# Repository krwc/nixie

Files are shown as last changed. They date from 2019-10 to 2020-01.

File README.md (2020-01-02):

# Another Nixie Clock, because why not?

When my journey into the world of electronics started, a friend of mine has shown me the
beautiful creations capable of presenting time using cold cathode tubes. Ever since then,
I wanted to create something similar, as it seemed like a pretty cool thing to do!

After some time, and two PCB revisions, the clock was actually useful, wasn't exploding,
and was looking quite neat overall to me.


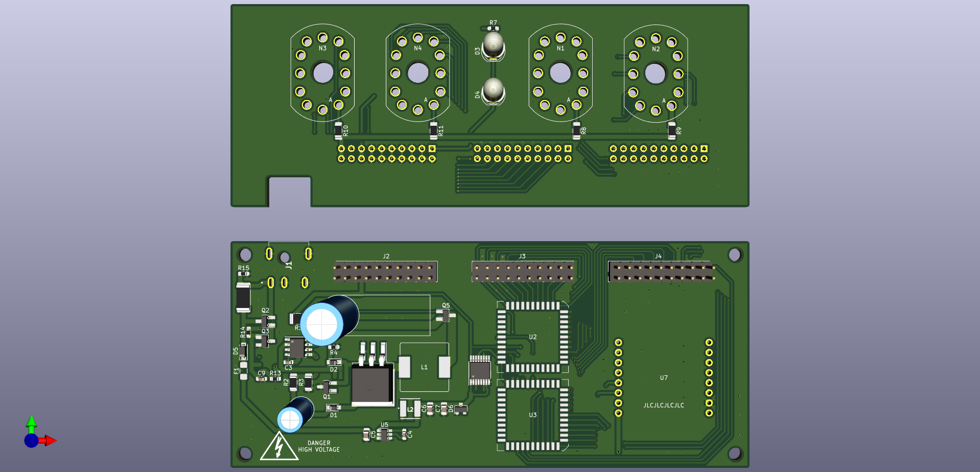
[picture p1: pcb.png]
PCB


# Safety

- The high voltage trace clearance is enforced to be 0.4mm
- There's a 1A slow fuse on the input
- There's a slow start mechanism implemented on the input, preventing high transient
  current during startup

Anyway, if you intend to use it, please do it on your own risk. Keep in mind, I'm not
a professional PCB designer, nor have a proper electrical education background.

# Acknolwedgements

- The power supply design is based on https://threeneurons.wordpress.com/nixie-power-supply/,
  and the datasheet of MC33063 itself. It is integrated into the main PCB.

- Wemos KiCad model was found somewhere on the internet, unfortunately I can't remember where
  exactly.

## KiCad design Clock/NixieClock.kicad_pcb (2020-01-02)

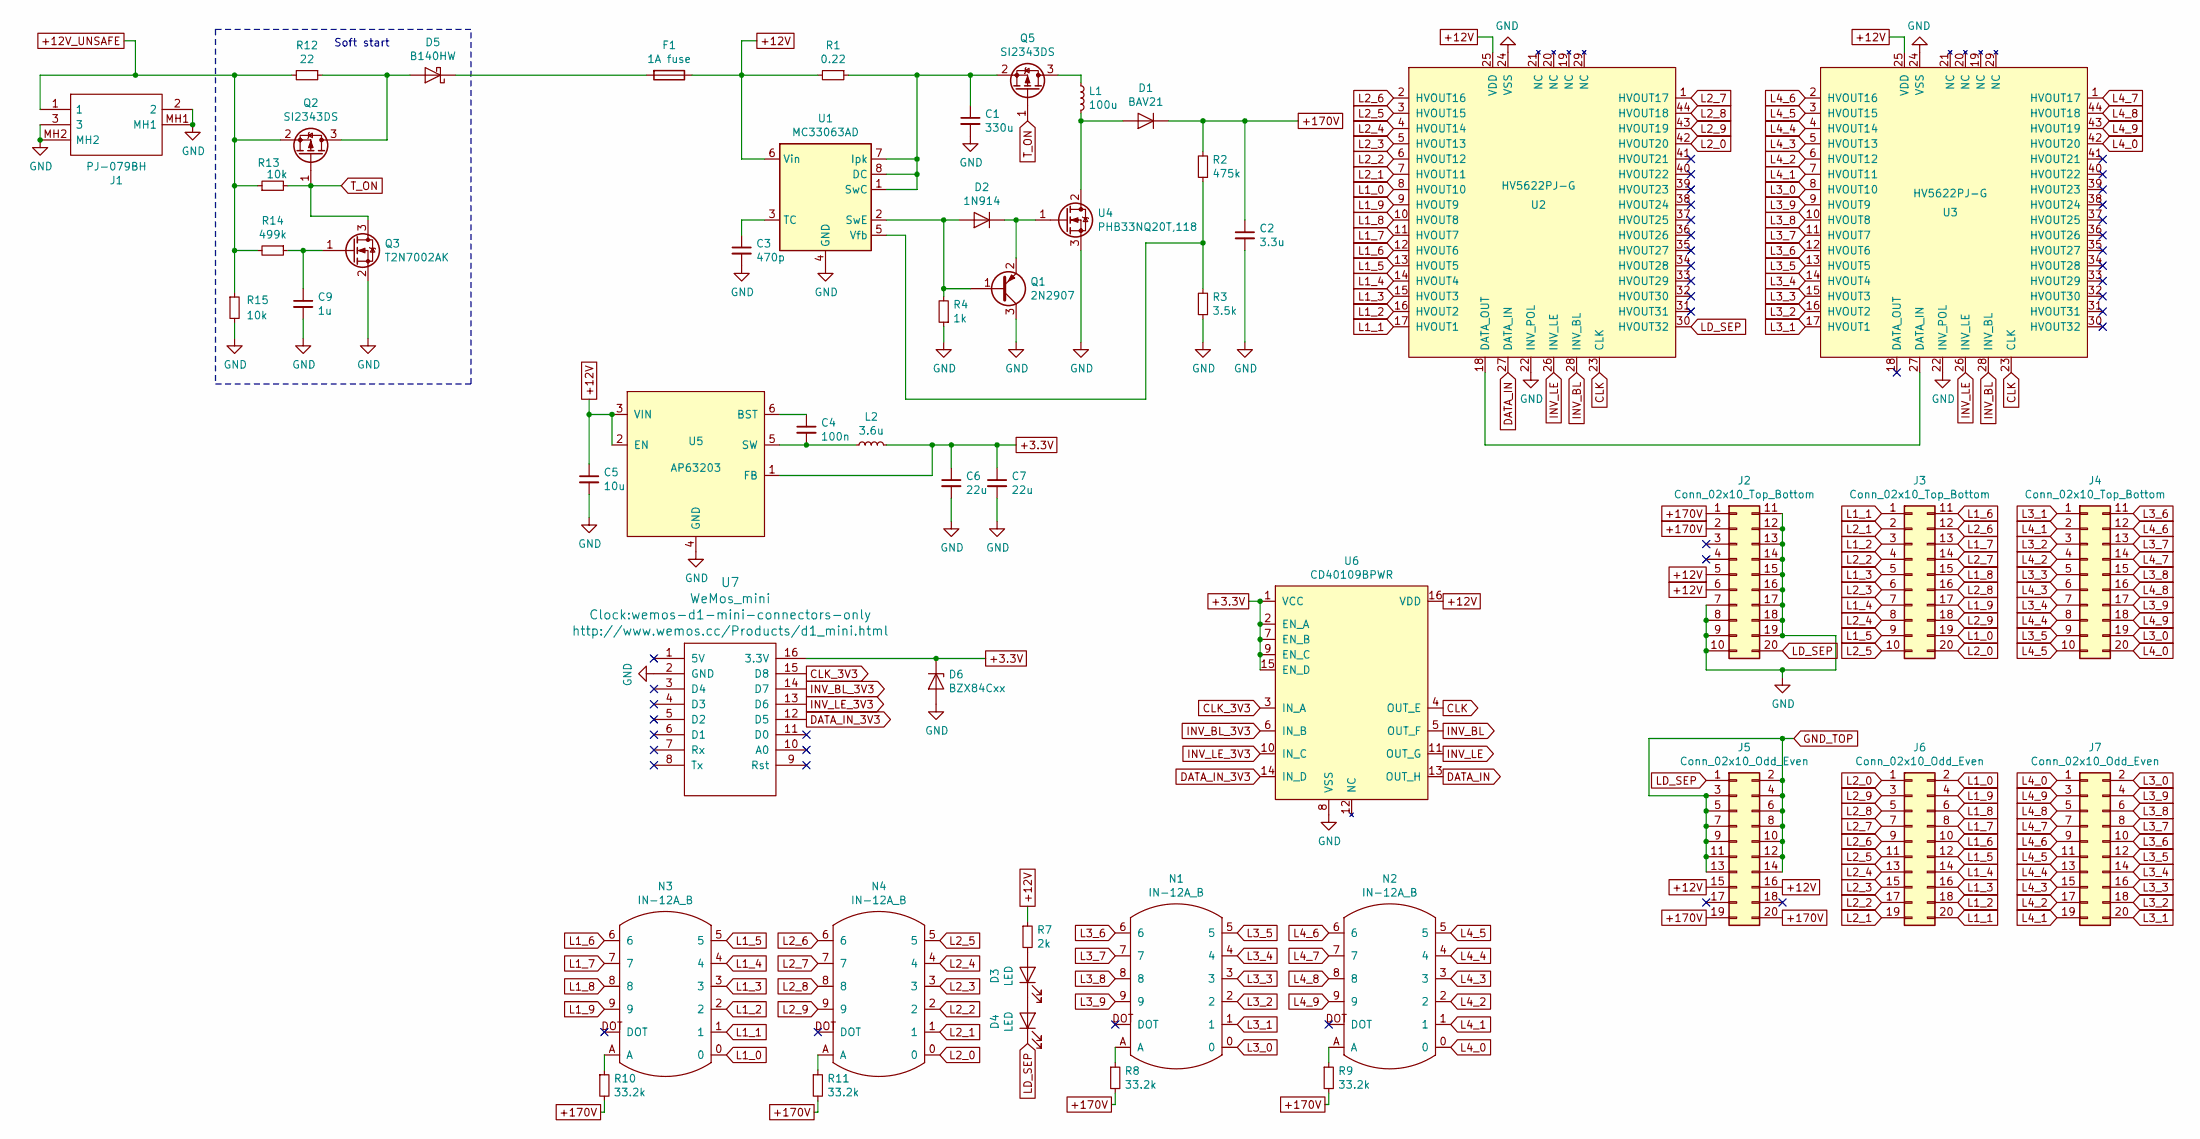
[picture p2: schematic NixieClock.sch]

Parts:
C1: 330u; C_Radial_D10.0mm_H20.0mm_P5.00mm
C2: 3.3u; C_Radial_D6.3mm_H11.0mm_P2.50mm
C3: 470p; C_0603_1608Metric
C4: 100n; C_0603_1608Metric_Pad1.05x0.95mm_HandSolder
C5: 10u; C_0805_2012Metric_Pad1.15x1.40mm_HandSolder
C6, C7: 22u; C_0805_2012Metric_Pad1.15x1.40mm_HandSolder
C9: 1u; C_0603_1608Metric_Pad1.05x0.95mm_HandSolder
D1: BAV21; D_SOD-323_HandSoldering
D2: 1N914; D_SOD-323_HandSoldering
D3, D4: LED; LED_D5.0mm_Clear
D5: B140HW; D_SOD-123
D6: BZX84Cxx; D_SOT-23_ANK
F1: 1A fuse; Fuse_1206_3216Metric_Pad1.42x1.75mm_HandSolder
J1: PJ-079BH; PJ079BH
J2, J3, J4: Conn_02x10_Top_Bottom; PinHeader_2x10_P2.54mm_Vertical
J5, J6, J7: Conn_02x10_Odd_Even; PinSocket_2x10_P2.54mm_Horizontal
L1: 100u; L_Bourns_SRR1210A
L2: 3.6u; SRN5040
N1, N2, N3, N4: IN-12A_B; IN12-A_B
Q1: 2N2907; SOT-23_Handsoldering
Q2, Q5: SI2343DS; SOT-23_Handsoldering
Q3: T2N7002AK; SOT-23_Handsoldering
R1: 0.22; R_1210_3225Metric_Pad1.42x2.65mm_HandSolder
R2: 475k; R_1206_3216Metric_Pad1.42x1.75mm_HandSolder
R3: 3.5k; R_1206_3216Metric_Pad1.42x1.75mm_HandSolder
R4: 1k; R_0603_1608Metric_Pad1.05x0.95mm_HandSolder
R7: 2k; R_0603_1608Metric_Pad1.05x0.95mm_HandSolder
R8, R9, R10, R11: 33.2k; R_1206_3216Metric_Pad1.42x1.75mm_HandSolder
R12: 22; R_2512_6332Metric_Pad1.52x3.35mm_HandSolder
R13, R15: 10k; R_0603_1608Metric_Pad1.05x0.95mm_HandSolder
R14: 499k; R_0603_1608Metric_Pad1.05x0.95mm_HandSolder
U1: MC33063AD; SOIC-8_3.9x4.9mm_P1.27mm
U2, U3: HV5622PJ-G; PLCC-44
U4: PHB33NQ20T,118; TO-263-3_TabPin2
U5: AP63203; TSOT-23-6
U6: CD40109BPWR; TSSOP-16_4.4x5mm_P0.65mm
U7: WeMos_mini; wemos-d1-mini-connectors-only

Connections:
+3.3V: C6.1, C7.1, D6.1 (K), L2.2, U5.1 (FB), U6.1 (VCC), U6.2 (EN_A), U6.7 (EN_B), U6.9 (EN_C), U6.15 (EN_D), U7.16 (3.3V)
+12V: C5.1, F1.1, J2.5, J2.6, J5.15, J5.16, R1.2, R7.1, U1.6 (Vin), U2.25 (VDD), U3.25 (VDD), U5.2 (EN), U5.3 (VIN), U6.16 (VDD)
+12V_UNSAFE: J1.1, Q2.2 (S), R12.2, R13.1, R14.2, R15.1
+170V: C2.1, D1.1 (K), J2.1, J2.2, J5.19, J5.20, R2.2, R8.2, R9.2, R10.2, R11.2
CLK: U2.23 (CLK), U3.23 (CLK), U6.4 (OUT_E)
CLK_3V3: U6.3 (IN_A), U7.15 (D8)
DATA_IN: U2.27 (DATA_IN), U6.13 (OUT_H)
DATA_IN_3V3: U6.14 (IN_D), U7.12 (D5)
GND: C1.2, C2.2, C3.2, C5.2, C6.2, C7.2, C9.2, D6.2 (A), J1.2, J1.3, J1.MH1, J1.MH2, J2.7, J2.8, J2.9, J2.10, J2.11, J2.12, J2.13, J2.14, J2.15, J2.16, J2.17, J2.18, J2.19, Q1.3 (C), Q3.2 (S), R3.1, R4.1, R15.2, U1.4 (GND), U2.22 (INV_POL), U2.24 (VSS), U3.22 (INV_POL), U3.24 (VSS), U4.3 (S), U5.4 (GND), U6.8 (VSS), U7.2 (GND)
GND_TOP: J5.2, J5.3, J5.4, J5.5, J5.6, J5.7, J5.8, J5.9, J5.10, J5.11, J5.12, J5.13, J5.14
INV_BL: U2.28 (INV_BL), U3.28 (INV_BL), U6.5 (OUT_F)
INV_BL_3V3: U6.6 (IN_B), U7.14 (D7)
INV_LE: U2.26 (INV_LE), U3.26 (INV_LE), U6.11 (OUT_G)
INV_LE_3V3: U6.10 (IN_C), U7.13 (D6)
L1_0: J3.19, J6.2, N3.0, U2.8 (HVOUT10)
L1_1: J3.1, J6.20, N3.1, U2.17 (HVOUT1)
L1_2: J3.3, J6.18, N3.2, U2.16 (HVOUT2)
L1_3: J3.5, J6.16, N3.3, U2.15 (HVOUT3)
L1_4: J3.7, J6.14, N3.4, U2.14 (HVOUT4)
L1_5: J3.9, J6.12, N3.5, U2.13 (HVOUT5)
L1_6: J3.11, J6.10, N3.6, U2.12 (HVOUT6)
L1_7: J3.13, J6.8, N3.7, U2.11 (HVOUT7)
L1_8: J3.15, J6.6, N3.8, U2.10 (HVOUT8)
L1_9: J3.17, J6.4, N3.9, U2.9 (HVOUT9)
L2_0: J3.20, J6.1, N4.0, U2.42 (HVOUT20)
L2_1: J3.2, J6.19, N4.1, U2.7 (HVOUT11)
L2_2: J3.4, J6.17, N4.2, U2.6 (HVOUT12)
L2_3: J3.6, J6.15, N4.3, U2.5 (HVOUT13)
L2_4: J3.8, J6.13, N4.4, U2.4 (HVOUT14)
L2_5: J3.10, J6.11, N4.5, U2.3 (HVOUT15)
L2_6: J3.12, J6.9, N4.6, U2.2 (HVOUT16)
L2_7: J3.14, J6.7, N4.7, U2.1 (HVOUT17)
L2_8: J3.16, J6.5, N4.8, U2.44 (HVOUT18)
L2_9: J3.18, J6.3, N4.9, U2.43 (HVOUT19)
L3_0: J4.19, J7.2, N1.0, U3.8 (HVOUT10)
L3_1: J4.1, J7.20, N1.1, U3.17 (HVOUT1)
L3_2: J4.3, J7.18, N1.2, U3.16 (HVOUT2)
L3_3: J4.5, J7.16, N1.3, U3.15 (HVOUT3)
L3_4: J4.7, J7.14, N1.4, U3.14 (HVOUT4)
L3_5: J4.9, J7.12, N1.5, U3.13 (HVOUT5)
L3_6: J4.11, J7.10, N1.6, U3.12 (HVOUT6)
L3_7: J4.13, J7.8, N1.7, U3.11 (HVOUT7)
L3_8: J4.15, J7.6, N1.8, U3.10 (HVOUT8)
L3_9: J4.17, J7.4, N1.9, U3.9 (HVOUT9)
L4_0: J4.20, J7.1, N2.0, U3.42 (HVOUT20)
L4_1: J4.2, J7.19, N2.1, U3.7 (HVOUT11)
L4_2: J4.4, J7.17, N2.2, U3.6 (HVOUT12)
L4_3: J4.6, J7.15, N2.3, U3.5 (HVOUT13)
L4_4: J4.8, J7.13, N2.4, U3.4 (HVOUT14)
L4_5: J4.10, J7.11, N2.5, U3.3 (HVOUT15)
L4_6: J4.12, J7.9, N2.6, U3.2 (HVOUT16)
L4_7: J4.14, J7.7, N2.7, U3.1 (HVOUT17)
L4_8: J4.16, J7.5, N2.8, U3.44 (HVOUT18)
L4_9: J4.18, J7.3, N2.9, U3.43 (HVOUT19)
LD_SEP: D4.1 (K), J2.20, J5.1, U2.30 (HVOUT32)
unnamed: C1.1, Q5.2 (S), R1.1, U1.1 (SwC), U1.7 (Ipk), U1.8 (DC)
unnamed: C3.1, U1.3 (TC)
unnamed: C4.1, U5.6 (BST)
unnamed: C4.2, L2.1, U5.5 (SW)
unnamed: C9.1, Q3.1 (G), R14.1
unnamed: D1.2 (A), L1.2, U4.2 (D)
unnamed: D2.1 (K), Q1.2 (E), U4.1 (G)
unnamed: D2.2 (A), Q1.1 (B), R4.2, U1.2 (SwE)
unnamed: D3.1 (K), D4.2 (A)
unnamed: D3.2 (A), R7.2
unnamed: D5.1 (K), F1.2
unnamed: D5.2 (A), Q2.3 (D), R12.1
unnamed: L1.1, Q5.3 (D)
unnamed: N1.A, R8.1
unnamed: N2.A, R9.1
unnamed: N3.A, R10.1
unnamed: N4.A, R11.1
unnamed: R2.1, R3.2, U1.5 (Vfb)
unnamed: U2.18 (DATA_OUT), U3.27 (DATA_IN)
T_ON: Q2.1 (G), Q3.3 (D), Q5.1 (G), R13.2

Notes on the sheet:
Soft start

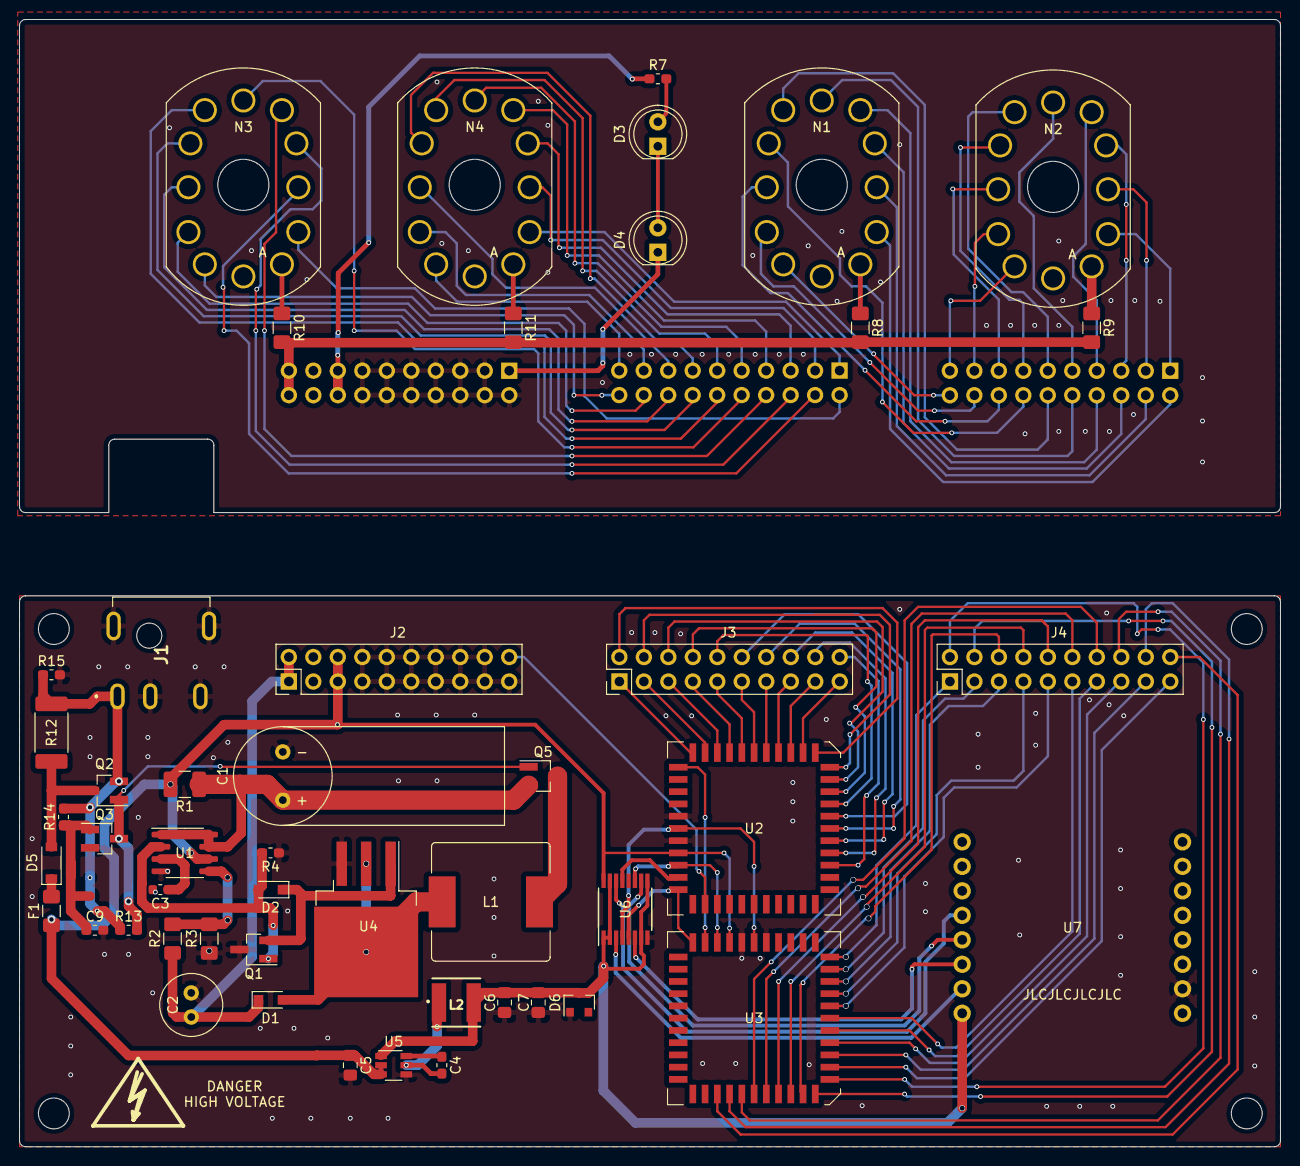
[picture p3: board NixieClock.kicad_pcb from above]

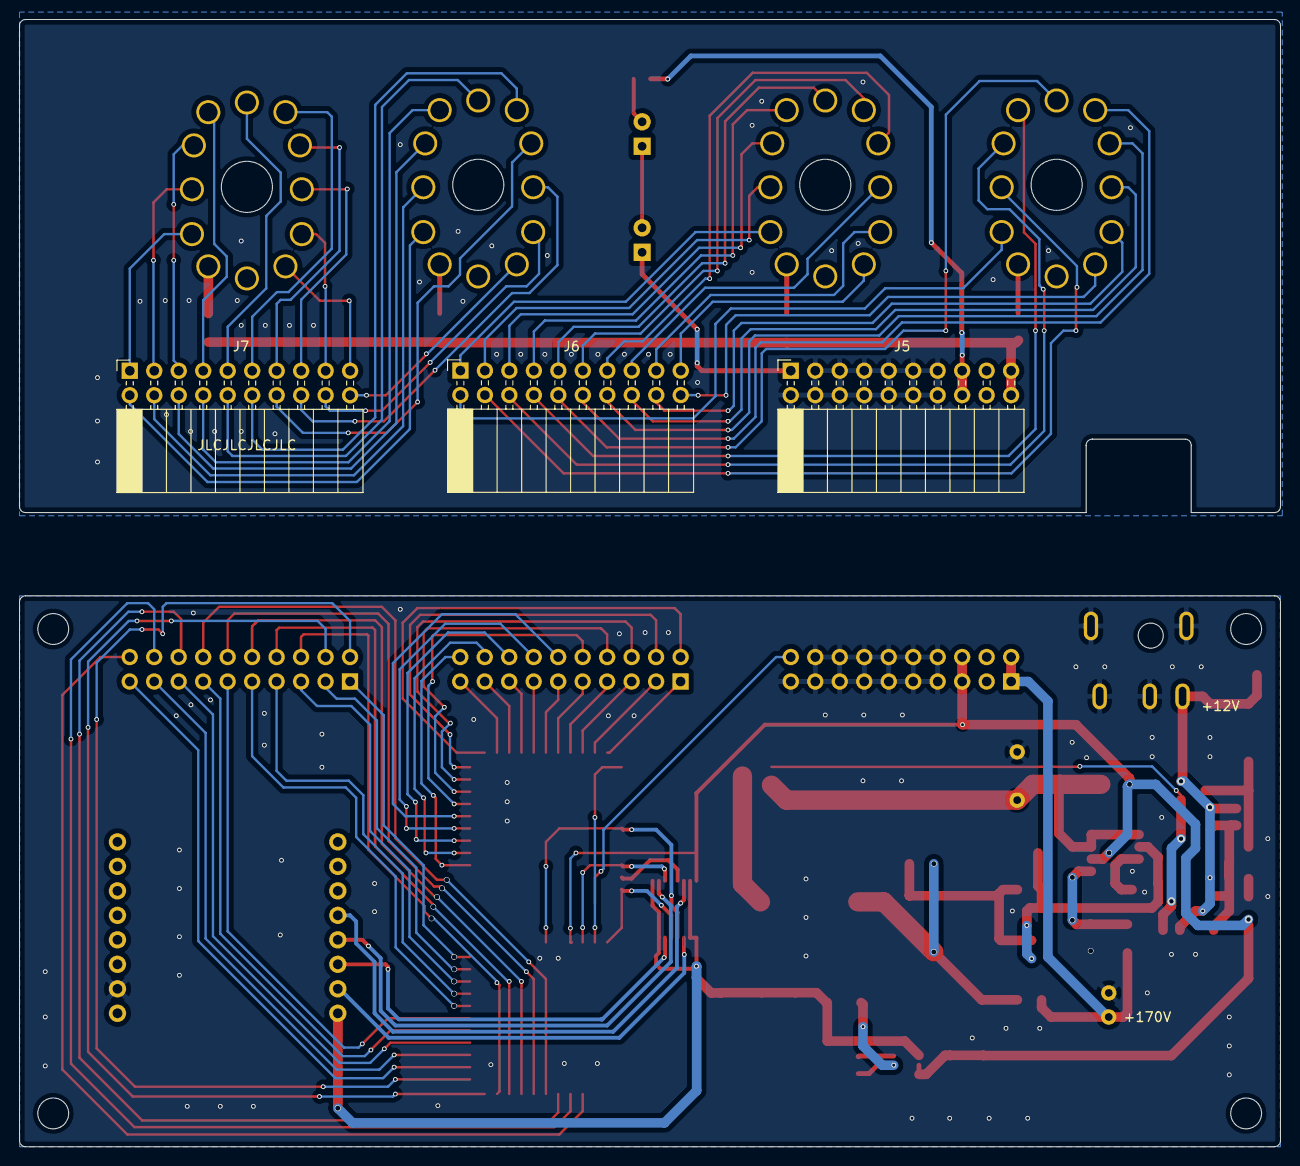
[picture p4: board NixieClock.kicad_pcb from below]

Board: 2 copper layers, 130.8 x 116.9 mm, 53 parts (3 on the bottom side), 75 nets.

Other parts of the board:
SYM1: SYM_Flash_Small; HighVoltage

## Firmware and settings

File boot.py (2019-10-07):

from machine import *
import network
import utime
import ntptime

WIFI_SSID=''
WIFI_PASS=''

clk = Pin(15, Pin.OUT)
bl = Pin(13, Pin.OUT)
le = Pin(12, Pin.OUT)
data = Pin(14, Pin.OUT)

clk.off()
bl.on()
le.on()
data.off()

def shift(value):
    data.value(value ^ 1)
    clk.on()
    clk.off()

def set_mask(bitmask):
    le.off()
    for i in range(64):
        shift((bitmask >> (63 - i)) & 0x1)
    le.on()

def set(v1, v2, v3, v4, dot):
    def vp(v):
        v %= 10
        if v == 0:
            v = 10
        return (1 << (v - 1))

    bitmask = 0
    bitmask |= vp(v1)
    bitmask |= (vp(v2) << 10)
    bitmask |= (vp(v3) << 32)
    bitmask |= (vp(v4) << 42)
    bitmask |= ((dot & 0x1) << 31)

    set_mask(bitmask)

def matrix():
    import random
    values = [0] * 5
    while True:
        sleep(300)
        index = random.getrandbits(8) % 4
        values[index] = random.getrandbits(8) % 10
        set(*values)

def cycle():
    while True:
        for i in range(10):
            set(i,i,i,i,0)

def settime(t):
    import machine
    import utime
    tm = utime.localtime(t)
    tm = tm[0:3] + (0,) + tm[3:6] + (0,)
    machine.RTC().datetime(tm)

cycle_count = 0
def connect_to_wifi():
    def cycle_nums(t):
        global cycle_count
        cycle_count += 1
        cycle_count %= 10
        i = cycle_count
        set(i, i, i, i, 0)

    tim_cycle = Timer(-1)
    tim_cycle.init(period=500, mode=Timer.PERIODIC, callback=cycle_nums)

    import network
    sta_if = network.WLAN(network.STA_IF)
    ap_if = network.WLAN(network.AP_IF)
    ap_if.active(True)
    sta_if.active(True)
    sta_if.connect(WIFI_SSID, WIFI_PASS)

    while not sta_if.isconnected():
        sleep(1000)

    ap_if.active(False)
    tim_cycle.deinit()

def timeloop():
    led = 1
    cycles = 0
    played = False
    while True:
	_, _, _, hour, minute, _, _, _ = utime.localtime()
	hour += 2
        hour %= 24
        v1 = hour // 10
        v2 = hour % 10
        v3 = minute // 10
        v4 = minute % 10

        set(v1,v2,v3,v4,led)
        sleep(900)
        led ^= 1
        cycles += 1

def sync_time_tim(t):
    while True:
        try:
            connect_to_wifi()
            settime(ntptime.time())
            return
        except:
            pass

set(8,8,8,8,0)
sync_time_tim(None)
tim_sync = Timer(-1)
tim_sync.init(period=300000, mode=Timer.PERIODIC, callback=sync_time_tim)

timeloop()

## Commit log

2019-08-19 Nixie clock implementation.
    [NixieClock.kicad_pcb, NixieClock.sch]
2019-10-07 Add v2.0 plots
    [NixieClock-B_Cu.gbr, NixieClock-B_Mask.gbr, NixieClock-B_Paste.gbr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]
2020-01-02 Remove a "fast-discharge" transistor, as it was not operating as intended due to emitter-base breakdown. It was pretty much optional anyway.
    [NixieClock.kicad_pcb, NixieClock.sch]
